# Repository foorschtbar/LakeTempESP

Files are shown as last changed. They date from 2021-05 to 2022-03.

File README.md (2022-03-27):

# LakeTempESP

WIP...

## Hardware 2021



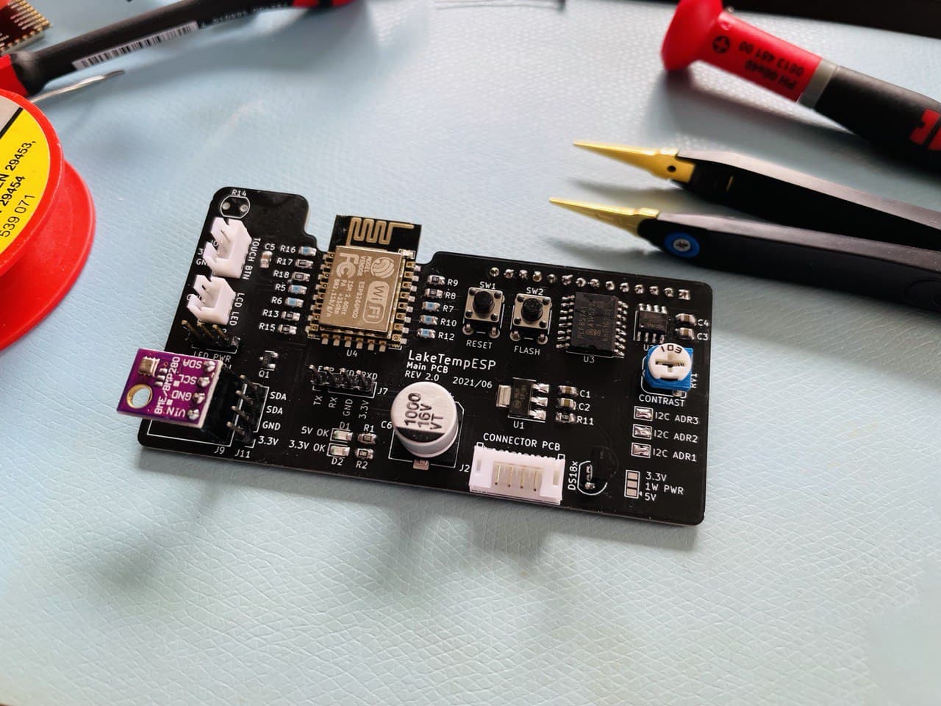
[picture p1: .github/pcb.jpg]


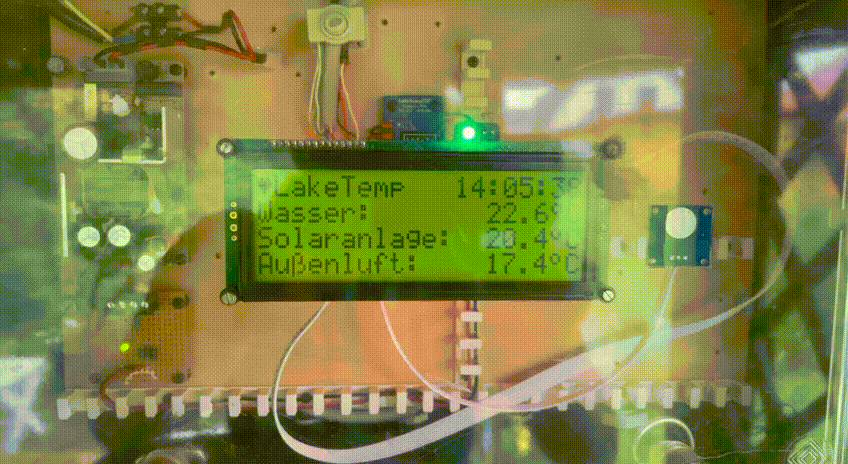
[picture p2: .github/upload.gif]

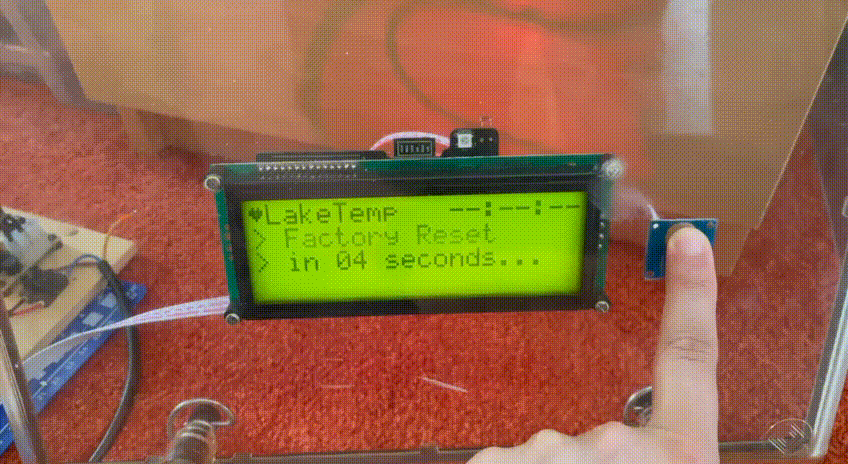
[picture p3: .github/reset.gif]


## Hardware 2011-2021

One of my first electronic projects 2011 based on a breadboard. It has lasted almost 10 years of continuous operation.

- Arduino Uno
- Ethernet Shield (WIZnet W1500)
- BT42008 LCD (HD44780 4x20)
- WiFi AP in Client Mode
- 5V Power Suppy for the Arduino
- 12V Power Suppy for the AccessPoint

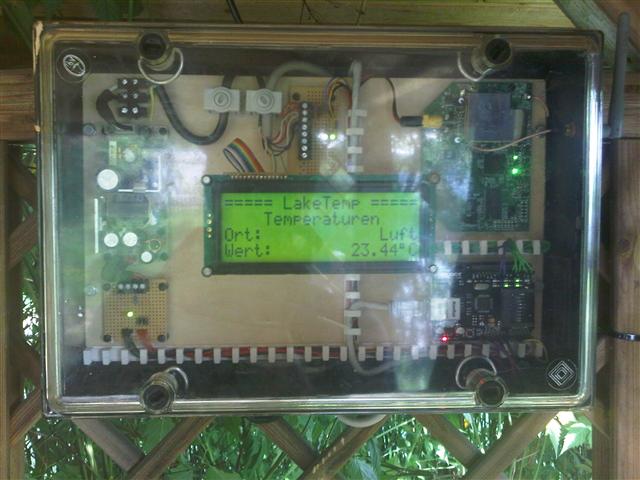
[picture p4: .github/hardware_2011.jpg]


## ToDo
- [ ] Fix random HW/SW watchdog reboots while uploading data
- [ ] Use Light Sensor for nice things
- [x] Trigger data upload from WebUI
- [x] Show last und next upload on Dashboard
- [x] Add MAC Address to JSON Msg
- [x] Flash/Blink LED on Upload
- [x] Flash/Blink LED on Button press
- [x] Fade LED in Idle State

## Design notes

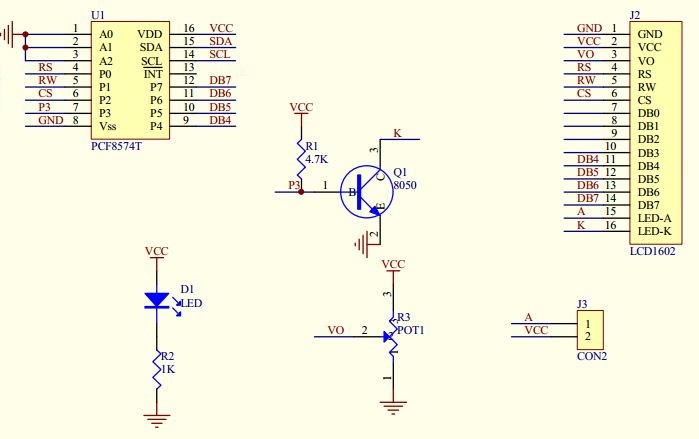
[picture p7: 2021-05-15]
_res/PCF8574_ErweiterungLCDisplayCircuit.jpg

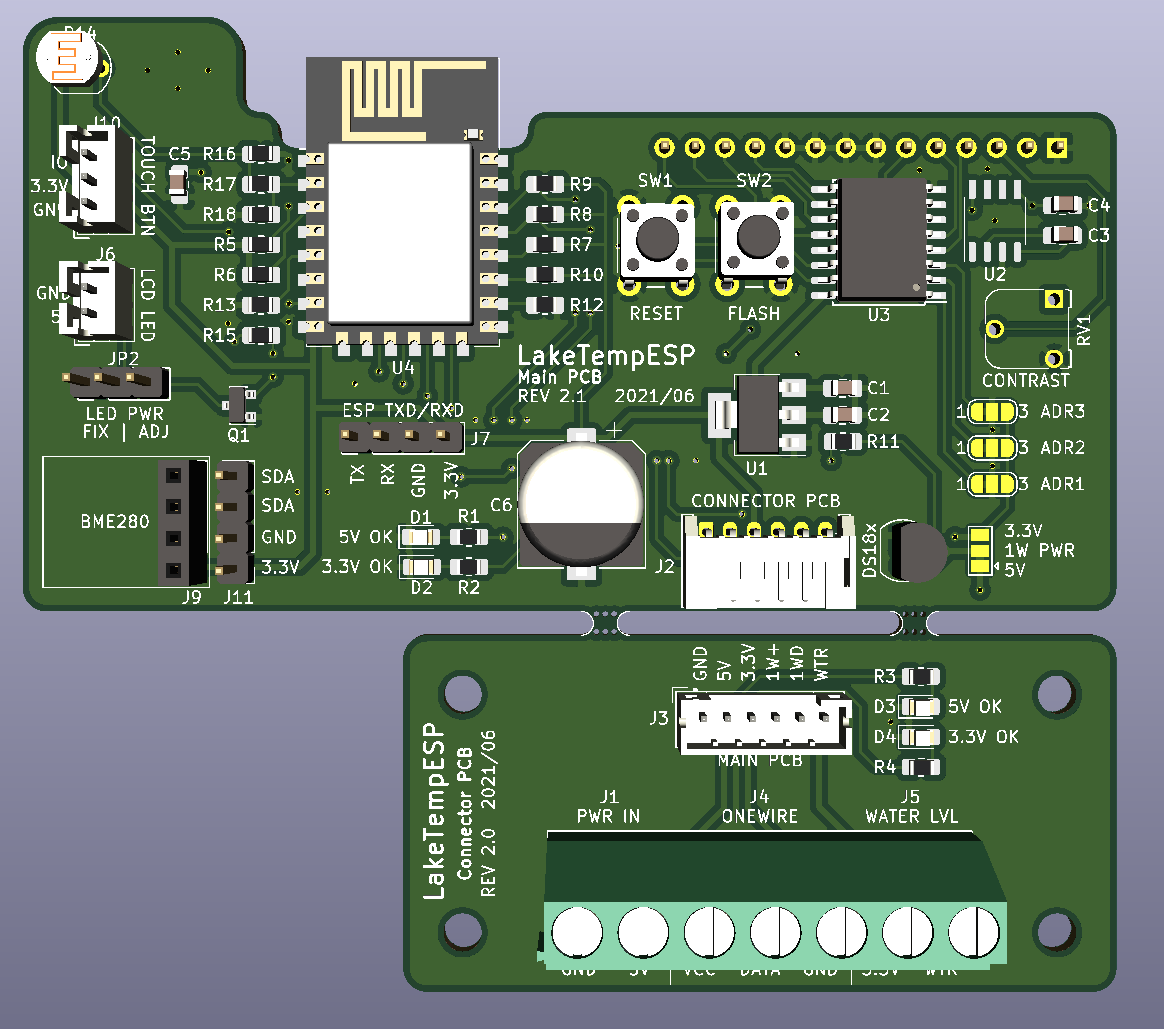
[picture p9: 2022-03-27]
.github/pcb_front.png

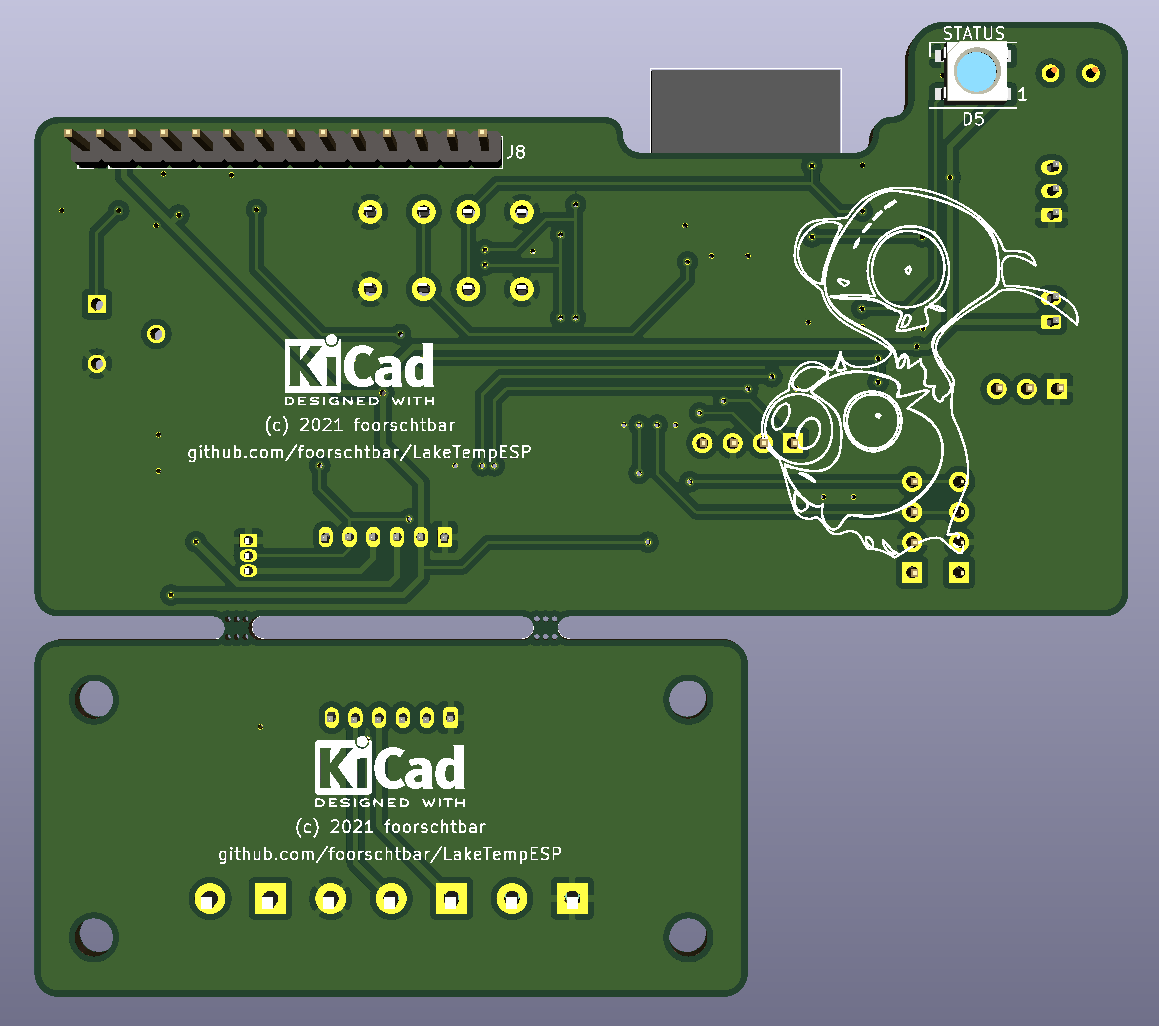
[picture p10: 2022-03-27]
.github/pcb_back.png

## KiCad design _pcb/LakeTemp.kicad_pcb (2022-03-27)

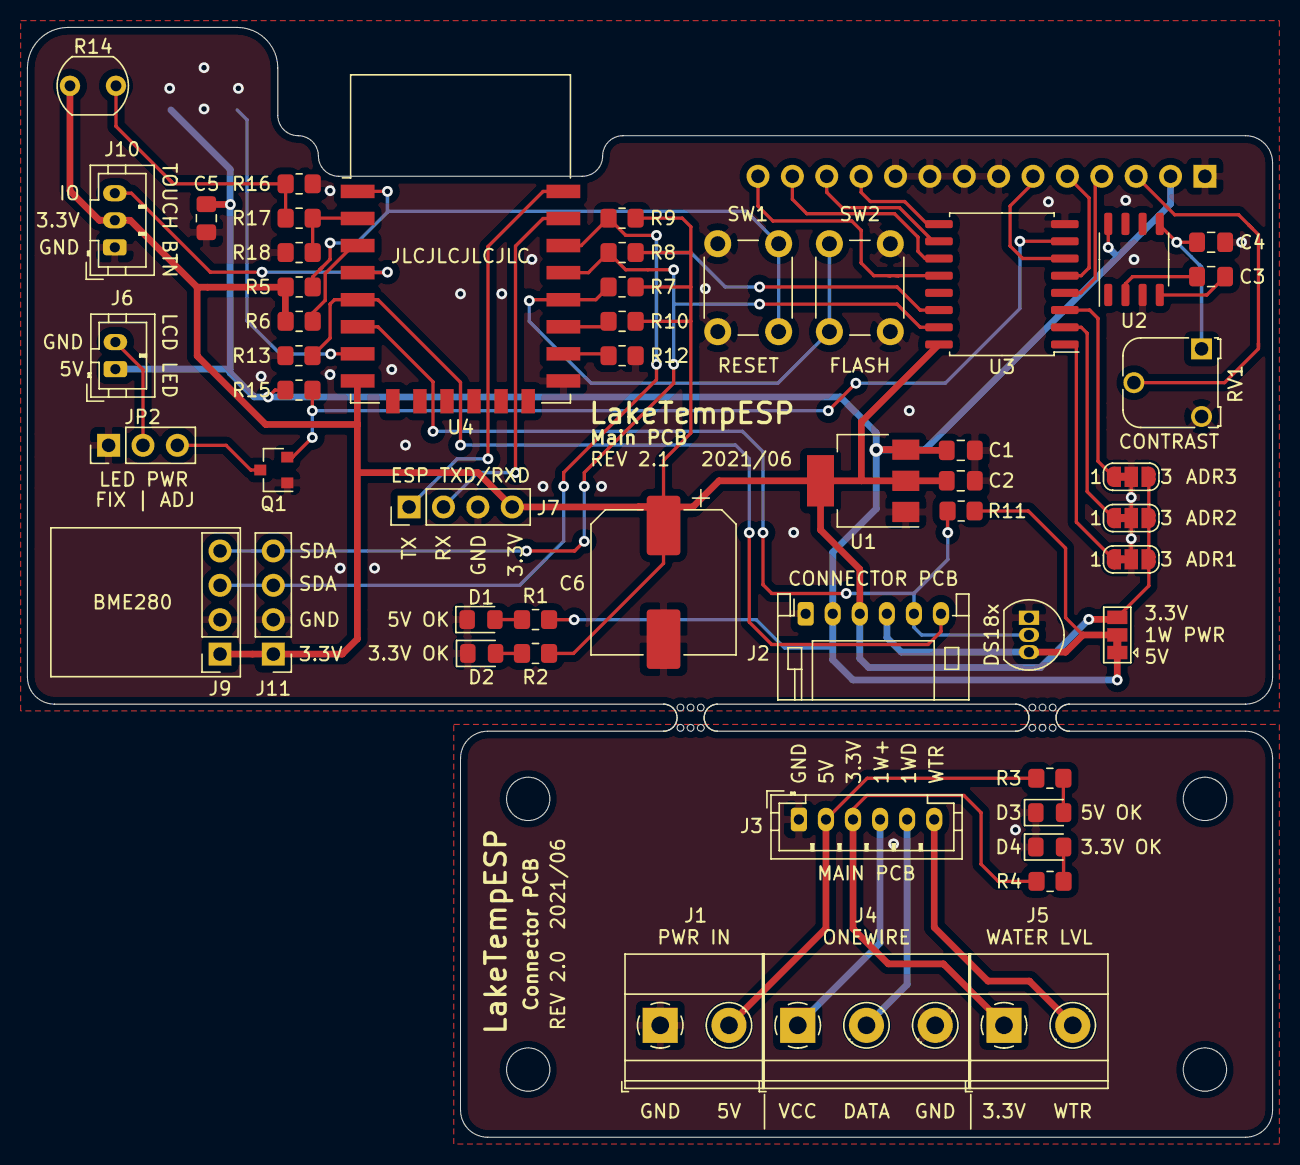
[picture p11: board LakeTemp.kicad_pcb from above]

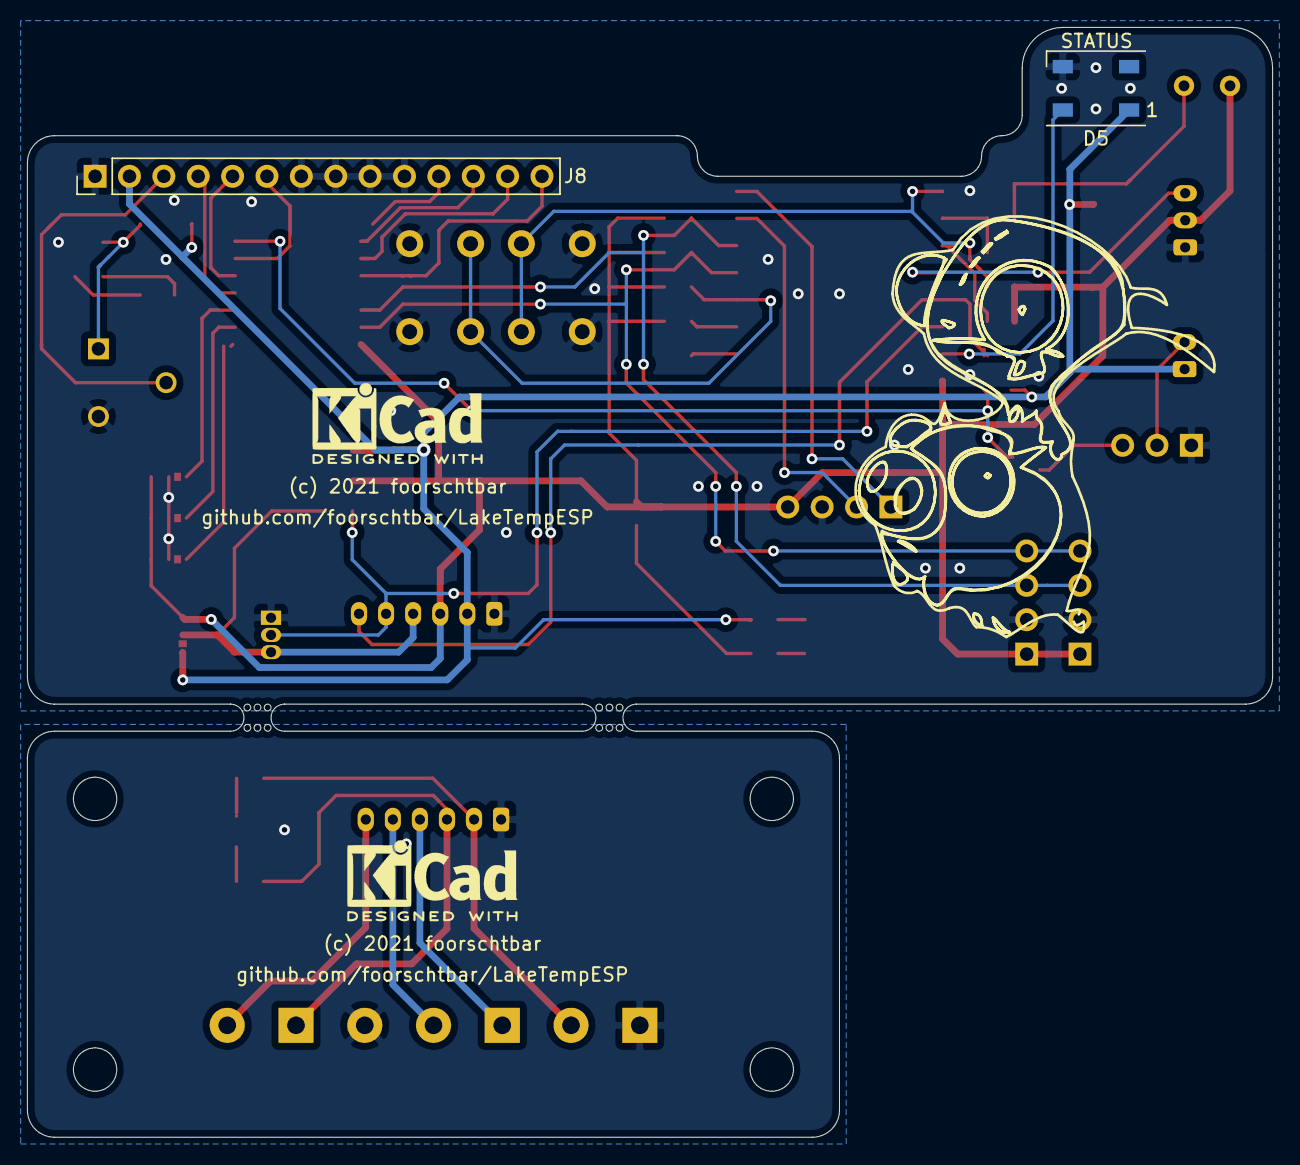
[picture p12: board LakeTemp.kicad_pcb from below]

Board: 2 copper layers, 92.0 x 82.0 mm, 56 parts (2 on the bottom side), 46 nets.

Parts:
ADR-A1, ADR-A2, ADR-A3: SolderJumper_2_Open; SolderJumper-3_P1.3mm_Bridged12_RoundedPad1.0x1.5mm_NumberL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
C1, C2, C3, C4: 10uF; C_0805_2012Metric_Pad1.18x1.45mm_HandSolder
C5: 100nF; C_0805_2012Metric_Pad1.18x1.45mm_HandSolder
C6: 1000uF; CP_Elec_10x10.5
D1, D3: PWR 5V; LED_0805_2012Metric_Pad1.15x1.40mm_HandSolder
D2, D4: PWR 3.3V; LED_0805_2012Metric_Pad1.15x1.40mm_HandSolder
D5: WS2812B; LED_WS2812B_PLCC4_5.0x5.0mm_P3.2mm
J1, J5: Conn_01x02_Female; TerminalBlock_Phoenix_MKDS-1,5-2-5.08_1x02_P5.08mm_Horizont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
J2: Conn_01x06_Male; JST_PH_S6B-PH-K_1x06_P2.00mm_Horizontal
J3: Conn_01x06_Male; JST_PH_B6B-PH-K_1x06_P2.00mm_Vertical
J4: Conn_01x03_Female; TerminalBlock_Phoenix_MKDS-1,5-3-5.08_1x03_P5.08mm_Horizont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
J6: Conn_01x02_Female; JST_PH_B2B-PH-K_1x02_P2.00mm_Vertical
J7: Conn_01x04_Male; PinHeader_1x04_P2.54mm_Vertical
J8: Conn_01x14_Female; PinHeader_1x14_P2.54mm_Vertical
J9: Conn_01x04_Female; PinSocket_1x04_P2.54mm_Vertical
J10: Conn_01x03_Male; JST_PH_B3B-PH-K_1x03_P2.00mm_Vertical
J11: Conn_01x04_Female; PinHeader_1x04_P2.54mm_Vertical
JP1: SolderJumper_3_Open; SolderJumper-3_P1.3mm_Bridged12_Pad1.0x1.5mm
JP2: SolderJumper_3_Open; PinHeader_1x03_P2.54mm_Vertical
Q1: S8050; SOT-23
R1, R3: 150; R_0805_2012Metric_Pad1.20x1.40mm_HandSolder
R2, R4: 68; R_0805_2012Metric_Pad1.20x1.40mm_HandSolder
R5, R6, R7, R10, R12, R16: 10K; R_0805_2012Metric_Pad1.20x1.40mm_HandSolder
R8, R9, R11, R13, R15: 4,7K; R_0805_2012Metric_Pad1.20x1.40mm_HandSolder
R14: GL5528; R_LDR_5.1x4.3mm_P3.4mm_Vertical
R17: 220K; R_0805_2012Metric_Pad1.20x1.40mm_HandSolder
R18: 100K; R_0805_2012Metric_Pad1.20x1.40mm_HandSolder
RV1: 10K; Potentiometer_Runtron_RM-065_Vertical
SW1: RESET; SW_PUSH_6mm_H5mm
SW2: FLASH; SW_PUSH_6mm_H5mm
U1: NCP1117-3.3_SOT223; SOT-223-3_TabPin2
U2: ICL7660; SOP-8_3.9x4.9mm_P1.27mm
U3: PCF8574; SOIC-16W_7.5x10.3mm_P1.27mm
U4: ESP-12E
U5: DS18B20; TO-92_Inline
mouse-bite-2mm-slot, mouse-bite-2mm-slot#2: VAL**; mouse-bite-2mm-slot

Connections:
+3V3: ADR-A1.3, ADR-A2.3, ADR-A3.3, C2.1, C6.1, J2.3, J7.4, J9.1, J10.2, J11.1, JP1.3, R2.1, R5.2, R6.2, R7.2, R8.1, R9.1, R10.2, R14.1, U1.2, U3.16, U4.8
+5V: C1.1, C5.1, D5.1, J2.2, J6.1, J8.2, JP1.1, R1.1, R15.1, U1.3, U2.8
ESP_RX: J7.2, U4.21
ESP_TX: J7.1, U4.22
GND: ADR-A1.2, ADR-A2.2, ADR-A3.2, C1.2, C2.2, C4.2, C5.2, C6.2, D1.1, D2.1, D5.3, J2.1, J7.3, J8.1, J8.7, J8.8, J8.9, J8.10, J9.2, J10.1, J11.2, JP2.1, Q1.1, R12.1, R13.2, R16.2, R18.1, RV1.3, SW1.1, SW2.1, U1.1, U2.3, U3.8, U4.15, U5.1
GND1: D3.1, D4.1, J1.1, J3.1, J4.3
LCD_CONTRAST: J8.3, RV1.2
LCD_DB4: J8.11, U3.9
LCD_DB5: J8.12, U3.10
LCD_DB6: J8.13, U3.11
LCD_DB7: J8.14, U3.12
LCD_E: J8.6, U3.6
LCD_LED: Q1.2, R15.2, U3.7
LCD_RS: J8.4, U3.4
LCD_RW: J8.5, U3.5
LDR: R14.2, R16.1, R17.2
unnamed: C3.1, U2.2
unnamed: C3.2, U2.4
unnamed: C4.1, RV1.1, U2.5
unnamed: D1.2, R1.2
unnamed: D2.2, R2.2
unnamed: D3.2, R3.2
unnamed: D4.2, R4.2
unnamed: J1.2, J3.2, R3.1
unnamed: J3.3, J5.1, R4.1
unnamed: J3.4, J4.1
unnamed: J3.5, J4.2
unnamed: J3.6, J5.2
unnamed: J6.2, JP2.2
unnamed: JP2.3, Q1.3
unnamed: R5.1, SW1.2, U4.1
unnamed: R6.1, U4.3
unnamed: R7.1, SW2.2, U4.18
unnamed: R10.1, U4.17
unnamed: R12.2, U4.16
unnamed: R17.1, R18.2, U4.2
ONEWIRE_BUS: J2.5, R11.2, U4.6, U5.2
ONEWIRE_PWR: J2.4, JP1.2, R11.1, U5.3
PCF_A0: ADR-A1.1, U3.1
PCF_A1: ADR-A2.1, U3.2
PCF_A2: ADR-A3.1, U3.3
SCL: J9.3, J11.3, R9.2, U3.14, U4.20
SDA: J9.4, J11.4, R8.2, U3.15, U4.19
TOUCH_IO: J10.3, U4.4
WATER_LEVEL: J2.6, R13.1, U4.5
WS2812B: D5.4, U4.7

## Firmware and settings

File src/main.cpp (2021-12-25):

#include "Arduino.h"
#include <ESP8266WiFi.h>
#include <ESP8266HTTPClient.h>
#include <WiFiClientSecureBearSSL.h>
#include <ESP8266WebServer.h>
#include <ESP8266HTTPUpdateServer.h>
#include <Wire.h>
#include <LiquidCrystal_I2C.h>
#include <WiFiUdp.h>
#include <OneWire.h>
#include <ArduinoJson.h>
#include <DallasTemperature.h> // http://milesburton.com/index.php/Dallas_Temperature_Control_Library
#include <Screens.h>
#include <NTPClient.h>
#include <Adafruit_Sensor.h>
#include <Adafruit_BME280.h>
#include <Adafruit_NeoPixel.h>
#include <LittleFS.h>
#include <WiFiManager.h>
#include "misc.h"

// ++++++++++++++++++++++++++++++++++++++++
//
// CONSTANTS
//
// ++++++++++++++++++++++++++++++++++++++++

// GPIOs
#define PIN_TOUCHSENSOR D0
#define PIN_WATERSENSOR D5
#define PIN_ONE_WIRE_BUS D6
#define PIN_WS2812B D7
#define PIN_LIGHTSENSOR A0

// LCD
#define LCD_COLUMS 20
#define LCD_ROWS 4
#define LCD_SPACE_SYMBOL 0x20 //space symbol from the LCD ROM, see p.9 of GDM2004D datasheet

// Other
#define MAX_NUM_SENSORS 10         //
#define RESET_COUNTDOWN 5          // How long the button needs to be pressed at startup to reset to factory defaults. Warning: Touchsensors goes to low after approx 5s continous pressing!
#define REFRESH_TIME 20            // After this time in sec pages refreshes
#define LED_BLINK_INTERVAL 200     //
#define LED_FADE_INTERVAL 100      //
#define SHOW_SCREEN_0_TIME 30      // How long screen #1 are shown
#define SHOW_SCREEN_1_TIME 5       // How long screen #2 are shown
#define SHOW_SCREEN_2_TIME 5       // How long screen #3 are shown
#define SENDDATA_INTERVAL 300000   // 5 Min (Regelmaesiger Upload)
#define REQ_SENSOR_INTERVAL 30000  // 30 sek
#define TIME_BUTTON_LONGPRESS 1000 // 1s
#define HEADER_TIME_WITH_SEC true  // Show secconds in header

// Constants - Misc
const char FIRMWARE_VERSION[] = "5.2";
const char COMPILE_DATE[] = __DATE__ " " __TIME__;

// ++++++++++++++++++++++++++++++++++++++++
//
// ENUMS
//
// ++++++++++++++++++++++++++++++++++++++++

enum class UploadStatus
{
  Unknown,
  Success,
  Failed
};

enum class WiFiStatus
{
  Unknown,
  Hotspot,
  Client
};

enum class LEDMode
{
  Normal,
  Blink,
  Fade
};

// ++++++++++++++++++++++++++++++++++++++++
//
// LIBS
//
// ++++++++++++++++++++++++++++++++++++++++

// LCD Setup
LiquidCrystal_I2C lcd(PCF8574_ADDR_A20_A10_A00, 4, 5, 6, 16, 11, 12, 13, 14, POSITIVE); // Only pins numbers: 4,5,6,16,11,12,13,14 are legal.

// Setup a oneWire instance to communicate with any OneWire devices (not just MLOCAL >>im/Dallas temperature ICs)
OneWire oneWire(PIN_ONE_WIRE_BUS);

// Pass our oneWire reference to Dallas Temperature.
DallasTemperature sensors(&oneWire);

// BME280 Sensor
Adafruit_BME280 bme; // I2C

// LCD Screen Switching
Screens screen(3, SHOW_SCREEN_0_TIME, SHOW_SCREEN_1_TIME, SHOW_SCREEN_2_TIME);

// Webserver
ESP8266WebServer server(80);

// Udpater
ESP8266HTTPUpdateServer httpUpdater;

// NeoPixel library
Adafruit_NeoPixel pixels(1, PIN_WS2812B, NEO_GRB + NEO_KHZ800);

// NTPCLient
WiFiUDP ntpUDP;
NTPClient timeClient(ntpUDP);

// ++++++++++++++++++++++++++++++++++++++++
//
// VARS
//
// ++++++++++++++++++++++++++++++++++++++++

// Buffers
String html;
char buff[255];

// Variables will change
uint8_t highwater = 0;                              //
bool forceSendData = true;                          //
unsigned long lastSendData = 0;                     //
unsigned long lastSensorVals = 0;                   // will store last time temps and water was updated
unsigned long buttonTimer = 0;                      // will store how long button was pressed
unsigned long ledTimer = 0;                         //
uint8_t numSensorsFound = 0;                        // number of oneWire sensors
bool lastTimeSyncWasSuccessfull = 0;                // Will store if last sync with NTP server was okay
float tempSensorValues[MAX_NUM_SENSORS];            // will store temp sensor values
DeviceAddress tempSensorAddresses[MAX_NUM_SENSORS]; // will store temp sensor addresses
UploadStatus uploadStatus = UploadStatus::Unknown;  //
WiFiStatus wifiStatus = WiFiStatus::Unknown;        //

typedef struct
{
  String hostname = "LakeTempESP";
  String ssid = "";
  String psk = "";
  String apiUrl = "";
  String apiKey = "";
  String username = "admin";
  String password = "admin";
  String ntpserver = "europe.pool.ntp.org";
  String note = "";
  int sensorIdxWater = 0;
  int sensorIdxSolar = 0;
  int sensorIdxAir = 0;
  int timeoffset = 7200;
} configData_t;
configData_t cfg;

// Colors
#define LED_BRIGHTNESS 100
#define COLOR_BLACK pixels.Color(0, 0, 0)
#define COLOR_BLUE pixels.Color(0, 0, 255)
#define COLOR_RED pixels.Color(255, 0, 0)
#define COLOR_GREEN pixels.Color(0, 255, 0)
#define COLOR_ORANGE pixels.Color(255, 200, 0)
#define COLOR_YELLOW pixels.Color(255, 255, 0)
#define COLOR_TOUCH pixels.Color(255, 255, 255)
uint32_t ledColor = COLOR_BLACK;
bool ledFirstLoop = true;
LEDMode ledMode = LEDMode::Normal;

void HTMLHeader(const char section[], unsigned int refresh = 0, const char url[] = "/");

// ++++++++++++++++++++++++++++++++++++++++
//
// MAIN CODE
//
// ++++++++++++++++++++++++++++++++++++++++

template <typename... Args>
void logf(const char *f, Args... args)
{
#ifdef DEBUG
  Serial.printf(f, args...);
#endif
}

String getUploadStatus()
{
  if (uploadStatus == UploadStatus::Success)
  {
    return "Success";
  }
  else if (uploadStatus == UploadStatus::Failed)
  {
    return "Failed";
  }
  else
  {
    return "Unknown";
  }
}

void showWEBAction()
{
  //setStatus(COLOR_TOUCH);
  // analogWrite(HWPIN_LED_WIFI, 0);
  // ledOneTime = millis();
}

void HTMLHeader(const char *section, unsigned int refresh, const char *url)
{
  char title[50];
  char hostname[50];
  WiFi.hostname().toCharArray(hostname, 50);
  snprintf(title, 50, "LakeTempESP@%s - %s", hostname, section);

  html = "<!DOCTYPE html>";
  html += "<html>\n";
  html += "<head>\n";
  html += "<meta name='viewport' content='width=600' />\n";
  if (refresh != 0)
  {
    html += "<META http-equiv='refresh' content='";
    html += refresh;
    html += ";URL=";
    html += url;
    html += "'>\n";
  }
  html += "<title>";
  html += title;
  html += "</title>\n";
  html += "<style>\n";
  html += "body {\n";
  html += " background-color: #EDEDED;\n";
  html += " font-family: Arial, Helvetica, Sans-Serif;\n";
  html += " Color: #333;\n";
  html += "}\n";
  html += "\n";
  html += "h1 {\n";
  html += "  background-color: #333;\n";
  html += "  display: table-cell;\n";
  html += "  margin: 20px;\n";
  html += "  padding: 20px;\n";
  html += "  color: white;\n";
  html += "  border-radius: 10px 10px 0 0;\n";
  html += "  font-size: 20px;\n";
  html += "}\n";
  html += "\n";
  html += "ul {\n";
  html += "  list-style-type: none;\n";
  html += "  margin: 0;\n";
  html += "  padding: 0;\n";
  html += "  overflow: hidden;\n";
  html += "  background-color: #333;\n";
  html += "  border-radius: 0 10px 10px 10px;";
  html += "}\n";
  html += "\n";
  html += "li {\n";
  html += "  float: left;\n";
  html += "}\n";
  html += "\n";
  html += "li a {\n";
  html += "  display: block;\n";
  html += "  color: #FFF;\n";
  html += "  text-align: center;\n";
  html += "  padding: 16px;\n";
  html += "  text-decoration: none;\n";
  html += "}\n";
  html += "\n";
  html += "li a:hover {\n";
  html += "  background-color: #111;\n";
  html += "}\n";
  html += "\n";
  html += "#main {\n";
  html += "  padding: 20px;\n";
  html += "  background-color: #FFF;\n";
  html += "  border-radius: 10px;\n";
  html += "  margin: 10px 0;\n";
  html += "}\n";
  html += "\n";
  html += "#footer {\n";
  html += "  border-radius: 10px;\n";
  html += "  background-color: #333;\n";
  html += "  padding: 10px;\n";
  html += "  color: #FFF;\n";
  html += "  font-size: 12px;\n";
  html += "  text-align: center;\n";
  html += "}\n";

  html += "table  {\n";
  html += "border-spacing: 0;\n";
  html += "}\n";

  html += "table td, table th {\n";
  html += "padding: 5px;\n";
  html += "}\n";

  html += "table tr:nth-child(even) {\n";
  html += "background: #EDEDED;\n";
  html += "}";

  html += "code {\n";
  html += "font-family : courier, courier new, serif;\n";
  html += "font-size: large;\n";
  html += "}";

  html += "input[type=\"submit\"], button {\n";
  html += "background-color: #333;\n";
  html += "border: none;\n";
  html += "color: white;\n";
  html += "padding: 5px 25px;\n";
  html += "text-align: center;\n";
  html += "text-decoration: none;\n";
  html += "display: inline-block;\n";
  html += "font-size: 16px;\n";
  html += "margin: 4px 2px;\n";
  html += "cursor: pointer;\n";
  html += "}\n";

  html += "input[type=\"submit\"]:hover, button:hover {\n";
  html += "background-color:#4e4e4e;\n";
  html += "}\n";

  html += "input[type=\"submit\"]:disabled, button:disabled {\n";
  html += "opacity: 0.6;\n";
  html += "cursor: not-allowed;\n";
  html += "}\n";

  html += ".inline {\n";
  html += "font-size: 10px !important;\n";
  html += "margin: 0 0 0 10px !important;\n";
  html += "vertical-align: middle ;\n";
  html += "}\n";

  html += "</style>\n";
  html += "</head>\n";
  html += "<body>\n";
  html += "<h1>";
  html += title;
  html += "</h1>\n";
  html += "<ul>\n";
  html += "<li><a href='/'>Home</a></li>\n";
  html += "<li><a href='/settings'>Settings</a></li>\n";
  html += "<li><a href='/wifiscan'>WiFi Scan</a></li>\n";
  html += "<li><a href='/fwupdate'>FW Update</a></li>\n";
  html += "<li><a href='/reboot'>Reboot</a></li>\n";
  html += "</ul>\n";
  html += "<div id='main'>";
}

void HTMLFooter()
{
  html += "</div>";
  html += "<div id='footer'>&copy; 2021 Fabian Otto - Firmware v";
  html += FIRMWARE_VERSION;
  html += " - Compiled at ";
  html += COMPILE_DATE;
  html += "</div>\n";
  html += "</body>\n";
  html += "</html>\n";
}

void SetConfigVars(DynamicJsonDocument &json)
{
  if (json.containsKey("ssid"))
  {
    cfg.ssid = json["ssid"].as<char *>();
  }

  if (json.containsKey("psk"))
  {
    cfg.psk = json["psk"].as<char *>();
  }

  if (json.containsKey("hostname"))
  {
    if (!json["hostname"].as<String>().isEmpty())
    {
      cfg.hostname = json["hostname"].as<String>();
    }
  }

  if (json.containsKey("sensorIdxAir"))
  {
    cfg.sensorIdxAir = json["sensorIdxAir"].as<int>();
  }

  if (json.containsKey("sensorIdxSolar"))
  {
    cfg.sensorIdxSolar = json["sensorIdxSolar"].as<int>();
  }

  if (json.containsKey("sensorIdxWater"))
  {
    cfg.sensorIdxWater = json["sensorIdxWater"].as<int>();
  }

  if (json.containsKey("username"))
  {
    cfg.username = json["username"].as<char *>();
  }

  if (json.containsKey("password"))
  {
    cfg.password = json["password"].as<char *>();
  }

  if (json.containsKey("apiKey"))
  {
    cfg.apiKey = json["apiKey"].as<char *>();
  }

  if (json.containsKey("apiUrl"))
  {
    cfg.apiUrl = json["apiUrl"].as<char *>();
  }

  if (json.containsKey("note"))
  {
    cfg.note = json["note"].as<char *>();
  }

  if (json.containsKey("ntpserver"))
  {
    cfg.ntpserver = json["ntpserver"].as<char *>();
  }

  if (json.containsKey("timeoffset"))
  {
    cfg.timeoffset = json["timeoffset"].as<int>();
  }
}

void SaveConfig()
{
  //save the custom parameters to FS

  DynamicJsonDocument json(1024);
  json["hostname"] = cfg.hostname;
  json["ssid"] = cfg.ssid;
  json["psk"] = cfg.psk;
  json["apiKey"] = cfg.apiKey;
  json["apiUrl"] = cfg.apiUrl;
  json["note"] = cfg.note;
  json["ntpserver"] = cfg.ntpserver;
  json["timeoffset"] = cfg.timeoffset;
  json["password"] = cfg.password;
  json["username"] = cfg.username;
  json["sensorIdxAir"] = cfg.sensorIdxAir;
  json["sensorIdxSolar"] = cfg.sensorIdxSolar;
  json["sensorIdxWater"] = cfg.sensorIdxWater;

  File configFile = LittleFS.open("/config.json", "w");
  serializeJson(json, configFile);
  configFile.close();

  logf("[SaveConfig] Saved\n");

  //end save
}

void LoadConfig()
{
  //file exists, reading and loading
  if (LittleFS.exists("/config.json"))
  {
    File configFile = LittleFS.open("/config.json", "r");

    if (configFile)
    {

      logf("[LoadConfig] Opened config file\n");

      DynamicJsonDocument json(1024);
      auto error = deserializeJson(json, configFile);

      if (error)
      {
        logf("[LoadConfig] deserializeJson() failed with code %s\n", error.c_str());
      }
      else
      {
        SetConfigVars(json);
        logf("[LoadConfig] Loaded\n");
      }
    }
  }
  else
  {

    logf("[LoadConfig] No Configfile, init new file\n");
    SaveConfig();
  }
}

void resetSettings()
{

  File configFile = LittleFS.open("/config.json", "w");
  if (!configFile)
  {

    logf("[resetSettings] Failed to open config file for reset\n");
  }
  configFile.println("");
  configFile.close();
  delay(300);
  ESP.restart();
  delay(300);
}

void setPixel(uint32_t c, uint b = LED_BRIGHTNESS)
{
  static uint32_t lastLEDColor;
  static uint lastLEDBrightness;

  if (lastLEDColor != c || lastLEDBrightness != b)
  {
    pixels.setPixelColor(0, c);
    pixels.setBrightness(b);
    pixels.show();
    lastLEDColor = c;
    lastLEDBrightness = b;
  }
}

void setStatus(uint32_t c, LEDMode mode = LEDMode::Normal)
{
  ledMode = mode;
  ledColor = c;
  ledFirstLoop = true;
  setPixel(c);
}

void setPixelToggle(uint32_t c1, uint32_t c2 = COLOR_BLACK)
{
  static bool last;

  if (ledFirstLoop)
  {
    last = true;
    ledFirstLoop = false;
  }

  if (last)
    setPixel(c1);
  else
    setPixel(c2);

  last = !last;
}

void setPixelFade(uint32_t c1, uint min)
{
  static uint bright;
  static bool direction; // true = down, false = up

  if (ledFirstLoop)
  {
    bright = LED_BRIGHTNESS;
    direction = true;
    ledFirstLoop = false;
  }

  setPixel(ledColor, bright);

  if (direction)
  {
    bright -= 5;
  }
  else
  {
    bright += 5;
  }

  // set direction for next loop
  if (bright >= LED_BRIGHTNESS)
  {
    direction = true; // down
  }
  else if (bright <= min)
  {
    direction = false; // up
  }
}

long dBm2Quality(long dBm)
{
  if (dBm <= -100)
    return 0;
  else if (dBm >= -50)
    return 100;
  else
    return 2 * (dBm + 100);
}

// function to print a device address
void printAddress(DeviceAddress deviceAddress, char *buffer, bool upperCase = false)
{
  int8_t off = 0;
  char out[17];
  for (int8_t i = 0; i < 8; i++)
  {
    off += snprintf(out + off, sizeof(out) - off, (upperCase ? "%02X" : "%02x"), deviceAddress[i]);
  }
  strcpy(buffer, out);
}

void initOneWireSensors()
{
  logf("[initOneWireSensors] Init sensor arrays...\n");

  for (int i = 0; i < MAX_NUM_SENSORS; i++)
  {
    tempSensorValues[i] = DEVICE_DISCONNECTED_C;
    for (int ii = 0; ii < 8; ii++)
    {
      tempSensorAddresses[i][ii] = 0x00;
    }
  }
  logf("[initOneWireSensors] Search Sensors...\n");

  numSensorsFound = sensors.getDeviceCount();
  logf("[initOneWireSensors] Found %d\n", numSensorsFound);

  if (numSensorsFound > 0)
  {

    // select the first sensor
    for (int i = 0; i < numSensorsFound; i++)
    {
      if (sensors.getAddress(tempSensorAddresses[i], i))
      {
        printAddress(tempSensorAddresses[i], buff);
      }
      else
      {
        strcpy(buff, "no address!");
      }
      logf("[initOneWireSensors] %d/%d: %s\n", i + 1, numSensorsFound, buff);
    }
  }
}

void getTemps()
{
  logf("[getTemps] Request temperatures...\n");

  sensors.requestTemperatures();

  for (uint8_t i = 0; i < numSensorsFound; i++)
  {
    tempSensorValues[i] = sensors.getTempC(tempSensorAddresses[i]);

    if (tempSensorValues[i] == DEVICE_DISCONNECTED_C)
    {
      logf("[getTemps] #%i: disconnected\n", i);
    }
    else
    {
      logf("[getTemps] #%i: %.01f °C\n", i, tempSensorValues[i]);
    }
  }
}

void lcdPrintFormatedTime(unsigned long inttime, boolean shorttime)
{

  char buffer[20];
  int days, hours, mins, secs;

  // Time to Sec
  inttime = inttime / 1000;

  // number of days is total number of seconds divided by 24 divided by 3600 !!! ACHTUNG inttime / (24*3600) geht nicht!!!!!!!!!!
  days = inttime / 86400;
  inttime = inttime % 86400;

  // Now, inttime is the remainder after subtracting the number of seconds
  // in the number of days
  hours = inttime / 3600;
  inttime = inttime % 3600;

  // Now, inttime is the remainder after subtracting the number of seconds
  // in the number of days and hours
  mins = inttime / 60;
  inttime = inttime % 60;

  // Now inttime is the number of seconds left after subtracting the number
  // in the number of days, hours and minutes. In other words, it is the
  // number of seconds.
  secs = inttime;

  if (shorttime)
  {
    snprintf_P(buffer, sizeof(buffer), PSTR("%02dm %02ds"), mins, secs);
  }
  else
  {
    if (days == 0)
    {
      snprintf_P(buffer, sizeof(buffer), PSTR(" %02dh %02dm %02ds"), hours, mins, secs);
    }
    else
    {
      snprintf_P(buffer, sizeof(buffer), PSTR("%03dd %02dh %02dm"), days, hours, mins);
    }
  }

  lcd.print(buffer);
}

void lcdPrintHeader()
{
  char buffer[10];
  lcd.setCursor(0, 0);
  if (screen.currentTick())
  {
    lcd.write(3);
  }
  else
  {
    lcd.write(4);
  }
  lcd.setCursor(1, 0);
  lcd.print(F("LakeTemp"));
  lcd.setCursor(11, 0);
  char tick = ':';

  if (screen.currentTick())
    tick = ' ';

  if (lastTimeSyncWasSuccessfull)
  {
    if (HEADER_TIME_WITH_SEC)
    {
      snprintf_P(buffer, sizeof(buffer), PSTR(" %02d%c%02d%c%02d"), timeClient.getHours(), tick, timeClient.getMinutes(), tick, timeClient.getSeconds());
    }
    else
    {
      snprintf_P(buffer, sizeof(buffer), PSTR("%02d%c%02d Uhr"), timeClient.getHours(), tick, timeClient.getSeconds());
    }
  }
  else
  {
    if (HEADER_TIME_WITH_SEC)
    {
      snprintf_P(buffer, sizeof(buffer), PSTR(" --%c--%c--"), tick, tick);
    }
    else
    {
      snprintf_P(buffer, sizeof(buffer), PSTR("--%c-- Uhr"), tick);
    }
  }
  lcd.print(buffer);
}

void sendData()
{
  bool failed = true;

  logf("[sendData] Start upload...\n");

  getTemps(); // Send the command to get temperatures
  lcd.clear();
  lcdPrintHeader();
  lcd.setCursor(0, 1);
  lcd.print(F("> Upload data..."));
  lcd.blink();

  // Allocate a temporary JsonDocument
  // Use arduinojson.org/v6/assistant to compute the capacity.
  StaticJsonDocument<500> jsondoc; //

  jsondoc["hostname"] = WiFi.hostname();
  jsondoc["firmware"] = FIRMWARE_VERSION;
  jsondoc["timestamp"] = timeClient.getEpochTime();
  jsondoc["wifi_rssi"] = WiFi.RSSI();
  jsondoc["light"] = analogRead(PIN_LIGHTSENSOR);
  jsondoc["highwater"] = highwater;
  jsondoc["uptime"] = millis();
  jsondoc["mac"] = WiFi.macAddress();

  // Add Temps
  char addressBuffer[16];
  JsonObject temps = jsondoc.createNestedObject("temps");
  for (uint8_t i = 0; i < numSensorsFound; i++)
  {
    if (tempSensorValues[i] != DEVICE_DISCONNECTED_C)
    {
      printAddress(tempSensorAddresses[i], addressBuffer);
      temps[addressBuffer] = tempSensorValues[i];
    }
  }

  yield();

  logf("[sendData] Sending: ");
#ifdef DEBUG
  serializeJson(jsondoc, Serial);
#endif
  logf("\n");

  char JSONmessageBuffer[500];
  serializeJson(jsondoc, JSONmessageBuffer, sizeof(JSONmessageBuffer));

  std::unique_ptr<BearSSL::WiFiClientSecure> client(new BearSSL::WiFiClientSecure);

  client->setInsecure(); //client->setFingerprint(fingerprint);

  HTTPClient https;

  logf("[sendData] HTTPS Client begin...\n");

  setStatus(COLOR_BLUE);

  if (https.begin(*client, cfg.apiUrl))
  { // HTTPS

    https.addHeader("Content-Type", "application/json"); // Add Header
    https.addHeader("X-API-Key", cfg.apiKey);            // Add Header

    logf("[sendData] HTTP POST data...\n");

    // start connection and send HTTP header
    int httpCode = https.POST(JSONmessageBuffer); // Send the request

    yield();

    // httpCode will be negative on error
    if (httpCode > 0)
    {
      // HTTP header has been send and Server response header has been handled
      logf("[sendData] HTTP Code: %d\n", httpCode);
      // file found at server
      if (httpCode == HTTP_CODE_OK || httpCode == HTTP_CODE_MOVED_PERMANENTLY)
      {
        failed = false;
        // logf("[sendData] HTTP Payload: %s", https.getString());
      }
    }
    else
    {
      logf("[sendData] HTTP POST... failed, error: %s\n", https.errorToString(httpCode).c_str());
    }

    https.end();
  }
  else
  {
    logf("[sendData] HTTP Unable to connect\n");
  }

  if (failed)
  {
    setStatus(COLOR_RED);
    lcd.noBlink();
    lcd.setCursor(0, 2);
    lcd.print(F("> failed!        "));
    delay(1000);
    screen.reset();
    uploadStatus = UploadStatus::Failed;
  }
  else
  {
    setStatus(COLOR_GREEN, LEDMode::Fade);
    lcd.noBlink();
    lcd.setCursor(0, 2);
    lcd.print(F("> synced!        "));
    delay(1000);
    screen.reset();
    uploadStatus = UploadStatus::Success;
  }

  logf("[sendData] finished\n");

  lastSendData = millis();
  forceSendData = false;
}
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
void loop()
{

  // Webserver
  server.handleClient();

  // Get temperatures from one wire sensors and waterlevel every x seconds
  if (millis() - lastSensorVals > REQ_SENSOR_INTERVAL || lastSensorVals == 0)
  {
    // Temps
    getTemps();

    // Water
    if (digitalRead(PIN_WATERSENSOR))
    {
      highwater = 1;
    }
    else
    {
      highwater = 0;
    }

    lastSensorVals = millis();
  }

  if (wifiStatus == WiFiStatus::Client)
  {
    // NTPCLient
    lastTimeSyncWasSuccessfull = timeClient.update();

    // handleButton
    handleButton();

    // Send Data block
    if (millis() - lastSendData >= SENDDATA_INTERVAL || forceSendData)
    {
      sendData();
    }

    screen.loop();

    // LCD
    lcdShow();
  }

  // LED Modes
  if (ledMode == LEDMode::Blink)
  {
    if (millis() - ledTimer > LED_BLINK_INTERVAL)
    {
      setPixelToggle(ledColor);
      ledTimer = millis();
    }
  }
  else if (ledMode == LEDMode::Fade)
  {
    if (millis() - ledTimer > LED_FADE_INTERVAL)
    {
      setPixelFade(ledColor, 20);
      ledTimer = millis();
    }
  }
  else
  {
    setPixel(ledColor);
  }
}

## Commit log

2021-05-15 Added PCB draft
    [LakeTemp.kicad_pcb, LakeTemp.sch]
2021-05-22 Update PCB
    [LakeTemp.kicad_pcb, LakeTemp.sch]
2021-05-22 Finished PCB v1.0
    [LakeTemp.kicad_pcb, LakeTemp.sch]
2021-05-22 Added Gerber files
    [LakeTemp-B_Cu.gbr, LakeTemp-B_Mask.gbr, LakeTemp-B_Paste.gbr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]
2021-06-05 Added Gerber files for Rev 1.0 PCB
    [LakeTemp-B_Cu.gbr, LakeTemp-B_Mask.gbr, LakeTemp-B_Paste.gbr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]
2021-06-05 Updated PCB to REV 2.0
    [LakeTemp-B_Cu.gbr, LakeTemp-B_Mask.gbr, LakeTemp-B_Paste.gbr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]
2021-06-05 Added Gerber-ZIP
2021-06-05 Added Labels to Aux I2C Connector
    [LakeTemp-B_Cu.gbr, LakeTemp-B_Mask.gbr, LakeTemp-B_Paste.gbr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]
2021-06-05 Added Gerber Files for Main PCB Only (REV 2.0)
2021-06-26 Added LED, Webserver, OTA, Screens and many more...
2021-06-28 Replace config file with GUI settings page
    [main.cpp]
2021-06-30 Extened Dashboard and upload msg
    - Trigger data upload from WebUI
    - Show last und next upload on Dashboard
    - Add MAC Address to JSON Msg
    - Flash/Blink LED on Upload
2021-07-02 Added some LED things
    - Flash LED on button press
    - Fade LED on Idle State
    - Serial output depends on build flag
2021-07-02 Replaced ifdef DEBUG with function
    [main.cpp]

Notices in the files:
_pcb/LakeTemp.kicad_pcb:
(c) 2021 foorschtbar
